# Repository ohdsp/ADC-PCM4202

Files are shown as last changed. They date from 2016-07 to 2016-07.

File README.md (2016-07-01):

# [Open Hardware DSP Platform](http://www.ohdsp.org)
## PCM4202 ADC with differential inputs
### Revision 2.0
###### ADC-PCM4202 (KiCad 4.0.2-stable)
---
# README
### Disclaimer
Copyright Paul Janicki 2016

Licensed under the TAPR Open Hardware License (www.tapr.org/OHL)

This documentation is distributed WITHOUT ANY EXPRESS OR IMPLIED WARRANTY, INCLUDING OF MERCHANTABILITY, SATISFACTORY QUALITY AND FITNESS FOR A PARTICULAR PURPOSE.

### What is this repository?

**Quick summary**

This is a differential stereo input PCM4202 ADC. This is designed as part the Open Hardware DSP Platform.  

The PCM4202 is a hardware controlled Delta-Sigma ADC.

This repository contains the KiCad design files, manufacturing Gerber/drill files, and PDF/drawing files for this board.

### What is the project folder structure?
Most folder names are self explanatory. Starting from the top level: \
*ADC-PCM4202*
+ *Bill of Materials*  - This contains the bill of materials in CVS, LibreOffice Calc and XML formats
+ *Drawings*
    + *PCB* - This contains SVG and PDF outputs of PCB copper layers and assembly drawings
    + *Schematics* - This contains the PDF schematic drawing
+ *Gerbers* - This contains the PCB Gerbers and drill drawings for manufacture, there is also a zip file ready to send to most manufacturers
+ *KiCad* - This contains the original KiCad schematic and PCB design files

### How do I get set up?

**Summary of set up**

1. Set your self up a directory on a local disk, something simple will make life easier (eg C:\Electronics on Windows as used here), but anywhere will do just fine.
2. Download the Kicad-Libs from [https://github.com/ohdsp/KiCad-Libs](https://github.com/ohdsp/KiCad-Libs) and place in C:\Electronics\Kicad-Libs (or your chosen folder) 
3. Create a OHDSP subdirectory in C:\Electronics (so C:\Electronics\OHDSP)
3. Download this project to C:\Electronics\OHDSP\ADC-PCM4202
4. Fire up Kicad
5. Open the main project file C:\Electronics\OHDSP\ADC-PCM4202\Schematics\ADC-PCM4202.pro
6. (Optional) Setup Pcbnew component library as below.
7. Do as you wish with the project, just keep it under TAPR Open Hardware License

Make sure your git setup doesn't exclude files used in the project (like .LIB files) or things may go wrong down the line.

**KiCad Library Configuration**

Note that you need to setup a Pcbnew library, but the eeschema libraries should work without any changes if you followed the instructions above.

To setup Pcbnew libraries:

In Pcbnew go to Preferences -> Footprint Libraries Manager. Under Global Libraries tab in the top list check if there is a nickname "MyKiCadLibs-Footprints" (usually at the end of the list). If there is but it points to the wrong place then change the Library Path to point to MyKiCadLibs-Footprints (eg C:\Electronics\KiCad-Libs\MyKiCadLibs-Footprints.pretty) folder for your setup. If this is missing you can use "Append with Wizard", choose "Files on my computer", click next, browse to library location (eg C:\Electronics\KiCad-Libs\MyKiCadLibs-Footprints.pretty) and select the folder MyKiCadLibs-Footprints.pretty, click next, check the Status column states OK and the Format is KiCad (if not re-download the library) and click next, then select "To global library configuration..." and click Finish.

To setup eeschema component libraries:
Either from KiCad project window go to Tools -> Run Library Editor OR under eeschema, go to Tools -> Library Editor. Then Preferences -> Component Libraries.

The top section "Component Library Files" should ideally contain only two libraries, the "power" library that ships with KiCad and "MyKiCadLibs-Lib" available from above. To setup MyKiCadLibs-Lib as a relative path under the "User defined search path" click add. Browse to the location of KiCad-Libs you download above (eg C:\Electronics\KiCad-Libs) and click "Select Folder". Say yes to add a relative path. Under component library files click add, browse to the KiCad-libs again (eg C:\Electronics\KiCad-Libs), select file "MyKiCadLibs-Lib.lib" and click open. MyKiCadLibs-lib should appear in the component library list with no path as it will be using the user defined search path set in the box below.

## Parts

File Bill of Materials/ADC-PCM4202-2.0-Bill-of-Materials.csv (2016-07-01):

Reference | Quantity | Footprint | Value | Description | Voltage | Size | Current | Type | Tolerance | Power
C201 C202 C210 C215 C217 | 5 | CAP-TH-D8mmP3.5mm | 220u | 'Aluminium electrolytic low impedance capacitor - eg Panasonic FC or FR parts | '25V | '3.5mm Pitch, 8mm Diameter | ' | ' | ' | '
C203 C204 C211 C218 C219 C224 | 6 | SMD-0805 | 22u | 'Ceramic capacitor | '25V | '0805 | ' | 'X5R | '20% | '
C205 C206 C214 C220 C221 C225 C228 C233 C234 C237 C238 C303 C307 C310 C311 C314 C318 C322 C323 C324 C327 C329 C330 C401 C403 C404 C406 C407 C412 C413 C422 C423 C426 C427 C428 C429 C438 C439 C442 C443 C444 C445 C448 C449 C454 C455 | 46 | SMD-0805 | 100n | 'Ceramic capacitor | '50V | '0805 | ' | 'X7R | '10% | '
C208 C209 C216 C222 C223 C229 C235 C306 C309 C312 C316 C319 C328 C405 C440 C441 C450 C451 C456 C457 | 20 | SMD-0805 | 10n | 'Ceramic capacitor | '50V | '0805 | ' | 'X7R | '10% | '
C207 C212 C213 C301 C315 C408 C409 C410 C411 | 9 | SMD-0805 | 100p | 'Ceramic capacitor | '50V | '0805 | ' | 'C0G | '5% | '
C226 C230 C302 C304 C317 C325 | 6 | CAP-TH-D6.3mmP2.5mm | 220u | 'Aluminium electrolytic low impedance capacitor - eg Panasonic FC or FR parts | '10V | '2.5mm Pitch, 6.3mm Diameter | ' | ' | ' | '
C227 C231 C305 C308 C320 C321 | 6 | SMD-0805 | 22u | 'Ceramic capacitor | '10V | '0805 | ' | 'X5R | '20% | '
C232 C236 C313 C424 C425 C430 C431 | 7 | SMD-0805 | 10u | 'Ceramic capacitor | '10V | '0805 | ' | 'X5R | '20% | '
C326 | 1 | SMD-0805 | N/F | 'Ceramic capacitor | '50V | '0805 | ' | 'X7R | '10% | '
C402 C446 C447 | 3 | SMD-1206 | 10u | 'Ceramic capacitor | '35V | '1206 | ' | 'X5R | '20% | '
C414 C417 C418 C421 | 4 | CAP-TH-D10mmP5mm | 100u | 'Aluminium electrolytic - Panasonic FC, Audio Grade, or Bipolar part | '50V | '5mm Pitch, 10mm Diameter | ' | ' | ' | '
C415 C416 C419 C420 | 4 | CAP_TH_5mm | 100n | 'Polyester capacitor - 5mm pitch - 5.5mm width max | '63V | '5mm | ' | 'Film | '10% | '
C432 C433 C434 C435 | 4 | SMD-0805 | 47p | 'Ceramic capacitor | '50V | '0805 | ' | 'C0G | '5% | '
C436 C437 | 2 | SMD-0805 | 2n7 | 'Ceramic capacitor | '50V | '0805 | ' | 'C0G | '5% | '
C452 C453 | 2 | CAP-TH-D6.3mmP2.5mm | 47u | 'Aluminium electrolytic low impedance capacitor - eg Panasonic FC or FR parts | '10V | '2.5mm Pitch, 6.3mm Diameter | ' | ' | ' | '
D201 D202 D203 D204 D205 D206 D208 | 7 | DIODE-SOD-123 | SS14L | 'SS14L 1A 40V Schottky rectifier - Sub-SMA (SOD-123) | ' | ' | ' | ' | ' | '
D207 | 1 | SMD-1206 | Green LED 1206 | 'Green LED - SMD - Vf 1.8V to 2.2V | ' | '1206 | ' | ' | ' | '
D301 D302 | 2 | SMD-1206 | Red LED 1206 | 'Red LED - SMD - Vf 1.8V to 2.2V | ' | '1206 | ' | ' | ' | '
FID201 FID202 FID203 FID204 | 4 | FID-1MM-3MM | MNT_HOLE | 'Fiducial Marker | ' | ' | ' | ' | ' | '
JP301 JP302 JP303 JP304 JP305 JP306 JP307 P301 | 8 | CONN_SIL_2_1MM | CONN_2x1 | '1x2 2.54mm pitch pin header | ' | ' | ' | ' | ' | '
L201 L202 L203 L301 L302 | 5 | SMD-0805 | 600R@100MHz | 'Ferrite bead, current rating 0.3A or higher, 600R@100MHz | ' | '0805 | '=>0.3A | ' | ' | '
MNT201 MNT202 MNT203 MNT204 | 4 | MNT_HOLE_3.2mm | MNT_HOLE | 'Mounting Hole | ' | ' | ' | ' | ' | '
P201 P202 P203 | 3 | CONN-2WAY-2.54mm-3.81mm-SPACING | CONN_2x1 | '2 way screw terminal, any 2.54mm to 3.81mm pitch part | ' | ' | ' | ' | ' | '
P302 | 1 | CONN_SIL_3_1MM | N/F | '1x3 2.54mm pitch pin header | ' | ' | ' | ' | ' | '
P303 | 1 | CONN_DIL_2X5_BOX_1MM | CONN_02X05 | '2x5 2.54mm pitch box header | ' | ' | ' | ' | ' | '
P401 P402 | 2 | CONN_SIL_3_1MM | CONN_3x1 | '1x3 2.54mm pitch pin header | ' | ' | ' | ' | ' | '
R201 R202 R203 R306 R309 | 5 | SMD-0805 | 47 | 'Thick or thin film resistor | ' | '0805 | ' | ' | '1% | '100mW
R204 | 1 | SMD-0805 | 2k2 | 'Thick or thin film resistor | ' | '0805 | ' | ' | '1% | '100mW
R205 | 1 | SMD-0805 | 6k8 | 'Thick or thin film resistor | ' | '0805 | ' | ' | '1% | '100mW
R206 R324 R326 | 3 | SMD-0805 | 470 | 'Thick or thin film resistor | ' | '0805 | ' | ' | '1% | '100mW
R301 R302 R303 R304 R305 R307 R308 | 7 | SMD-0805 | 10k | 'Thick or thin film resistor | ' | '0805 | ' | ' | '1% | '100mW
R311 | 1 | SMD-0805 | 100k | 'Thick or thin film resistor | ' | '0805 | ' | ' | '1% | '100mW
R312 R318 R319 R320 R321 R322 | 6 | SMD-0805 | N/F | 'Thick or thin film resistor | ' | '0805 | ' | ' | '1% | '100mW
R313 R314 R315 | 3 | SMD-0805 | 0 | 'Thick or thin film resistor | ' | '0805 | ' | ' | '1% | '100mW
R316 | 1 | SMD-0805 | 75 | 'Thick or thin film resistor | ' | '0805 | ' | ' | '1% | '100mW
R317 | 1 | SMD-0805 | 100R | 'Thick or thin film resistor | ' | '0805 | ' | ' | '1% | '100mW
R310 R323 R325 | 3 | SMD-0805 | 1k | 'Thick or thin film resistor | ' | '0805 | ' | ' | '1% | '100mW
R403 R404 R405 R406 | 4 | SMD-1206 | 100 | 'MELF0204 1% =>250mW or 1206 1% =>250mW | ' | '1206 | ' | ' | '1% | '250mW
R407 R408 R409 R410 | 4 | SMD-1206 | 100k | 'MELF0204 1% =>250mW or 1206 1% =>250mW | ' | '1206 | ' | ' | '1% | '250mW
R411 R412 R413 R414 R415 R416 R417 R418 | 8 | SMD-1206 | 4k7 | 'MELF0204 1% =>250mW or 1206 1% =>250mW | ' | '1206 | ' | ' | '1% | '250mW
R401 R402 R419 R420 R421 R422 | 6 | SMD-1206 | 10k | 'MELF0204 1% =>250mW or 1206 1% =>250mW | ' | '1206 | ' | ' | '1% | '250mW
R423 R424 R425 R426 | 4 | SMD-1206 | 40R2 | 'MELF0204 1% =>250mW or 1206 1% =>250mW | ' | '1206 | ' | ' | '1% | '250mW
R427 R428 R429 R430 | 4 | SMD-1206 | 1k | 'MELF0204 1% =>250mW or 1206 1% =>250mW | ' | '1206 | ' | ' | '1% | '250mW
TR301 TR302 | 2 | IC-SOT23 | BC847 | '45 V, 100 mA NPN general-purpose transistors | ' | ' | ' | ' | ' | '
U201 | 1 | IC-SOT-223 | TLV1117LV33DCY | 'TLV1117LV 1-A, Positive Fixed-Voltage, Low-Dropout Regulator - Fixed 3V3 | ' | ' | ' | ' | ' | '
U202 | 1 | IC-SOT223-6 | TPS7A4501 | 'TPS7A45xx Low-Noise Fast-Transient-Response 1.5-A Low-Dropout Voltage Regulator - Adjustable | ' | ' | ' | ' | ' | '
U301 | 1 | IC-SSOP28 | PCM4202DBT | 'High-Performance 24-Bit, 216kHz Sampling Stereo Audio Analog-to-Digital Converter | ' | ' | ' | ' | ' | '
U302 | 1 | IC-SOT143 | ADM811TART | 'Microprocessor Supervisory - 3V08 Typical Threshold | ' | ' | ' | ' | ' | '
U401 U402 U403 U404 U405 U406 | 6 | IC_SOIC_8 | TLE2071 | 'LOW-NOISE HIGH-SPEED JFET-INPUT OPERATIONAL AMPLIFIERS - SINGLE | ' | ' | ' | ' | ' | '

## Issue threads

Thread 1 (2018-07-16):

I don't think the preamp section does what it should do

mrnuke, 2018-07-16:
I'd expect the preamp to the ADC to do several things, of which:

1. Shift an input voltage of 0V to Vcom
2. Maintain phase relationship between input and output signals

I'll take one half of the preamp for demonstration purposes:

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

Under normal operating conditions Vc = V+, and the opamp does its thing to keep V- = Vc. Looking at a current going throgh R411 and R419 we get:

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

We can solve this for Vo, and rearrange things a bit to get:

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

It could be that I'm just reading the schematic completely wrong, but I doubt it. This fails point (1) because it applies a non-unity gain to Vcom. It fails point (2) because it inverts the phase of the signal -- negative gain wrt Vi.

(2) is easy to fix, just swap the ANAL+/- connections.
(1) can be fixed by applying Vcom to a summing junction at the inverting input. However, in that case, it's probably better to use an instrumentation amplifier topology, and Vcom might need to be buffered

ohdsp, 2018-07-16:
C414 gives unity gain at DC. See examples for chips like the PCM4220.

mrnuke, 2018-07-16:
Oh, DUH. You are right. I can't ignore C414 like I did, because it blocks DC currents. Thank you for clarifying this, and my apologies for raising a false alarm. There's still the phase reversal issue (which is correctly handled in the PCM4220 example circuit).

ohdsp, 2018-07-16:
PCM4220 has both inverting/non-inverting options as examples. You do not need to maintain the phase, and with a differential input who's to say it was wired correctly anyway. With a DSP in the middle you can just hit the invert button. There many technical arguments for inverting/non-inverting. In this instance I can achieve gains <1 if needed.

Closed 2018-07-16.

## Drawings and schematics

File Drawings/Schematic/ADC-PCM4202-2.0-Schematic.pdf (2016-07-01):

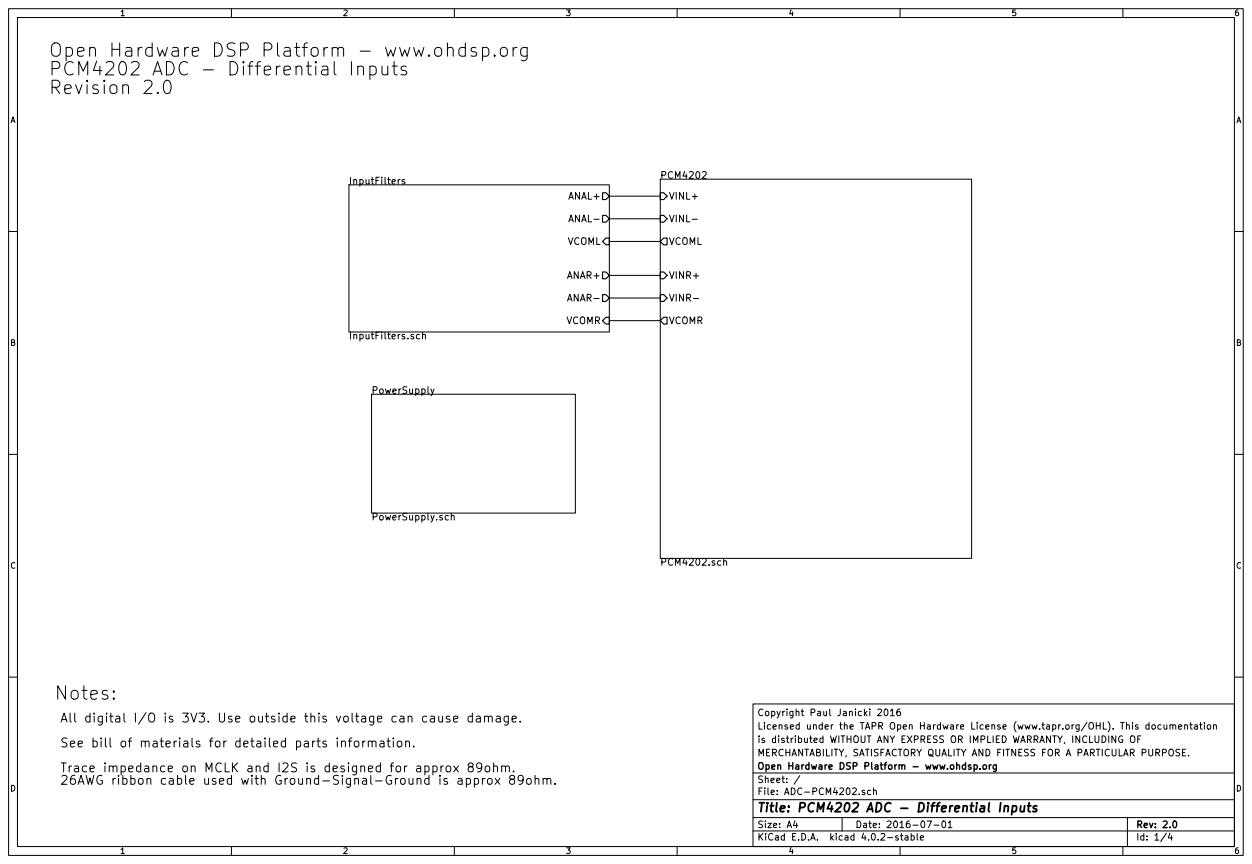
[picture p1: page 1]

Open Hardware DSP Platform - www.ohdsp.org
PCM4202 ADC - Differential Inputs
Revision 2.0

PCM4202
PCM4202.sch VINR+ VINR- VINL+ VINL- VCOML

VCOML ANAL+ ANAL- ANAR+ ANAR- VCOMR

All digital I/O is 3V3. Use outside this voltage can cause damage.
See bill of materials for detailed parts information.
Trace impedance on MCLK and I2S is designed for approx 89ohm.
26AWG ribbon cable used with Ground-Signal-Ground is approx 89ohm.

Copyright Paul Janicki 2016
Licensed under the TAPR Open Hardware License (www.tapr.org/OHL). This documentation
is distributed WITHOUT ANY EXPRESS OR IMPLIED WARRANTY, INCLUDING OF
MERCHANTABILITY, SATISFACTORY QUALITY AND FITNESS FOR A PARTICULAR PURPOSE.
File: ADC-PCM4202.sch Sheet: / Open Hardware DSP Platform - www.ohdsp.org

Id: 1/4 Title: PCM4202 ADC - Differential Inputs

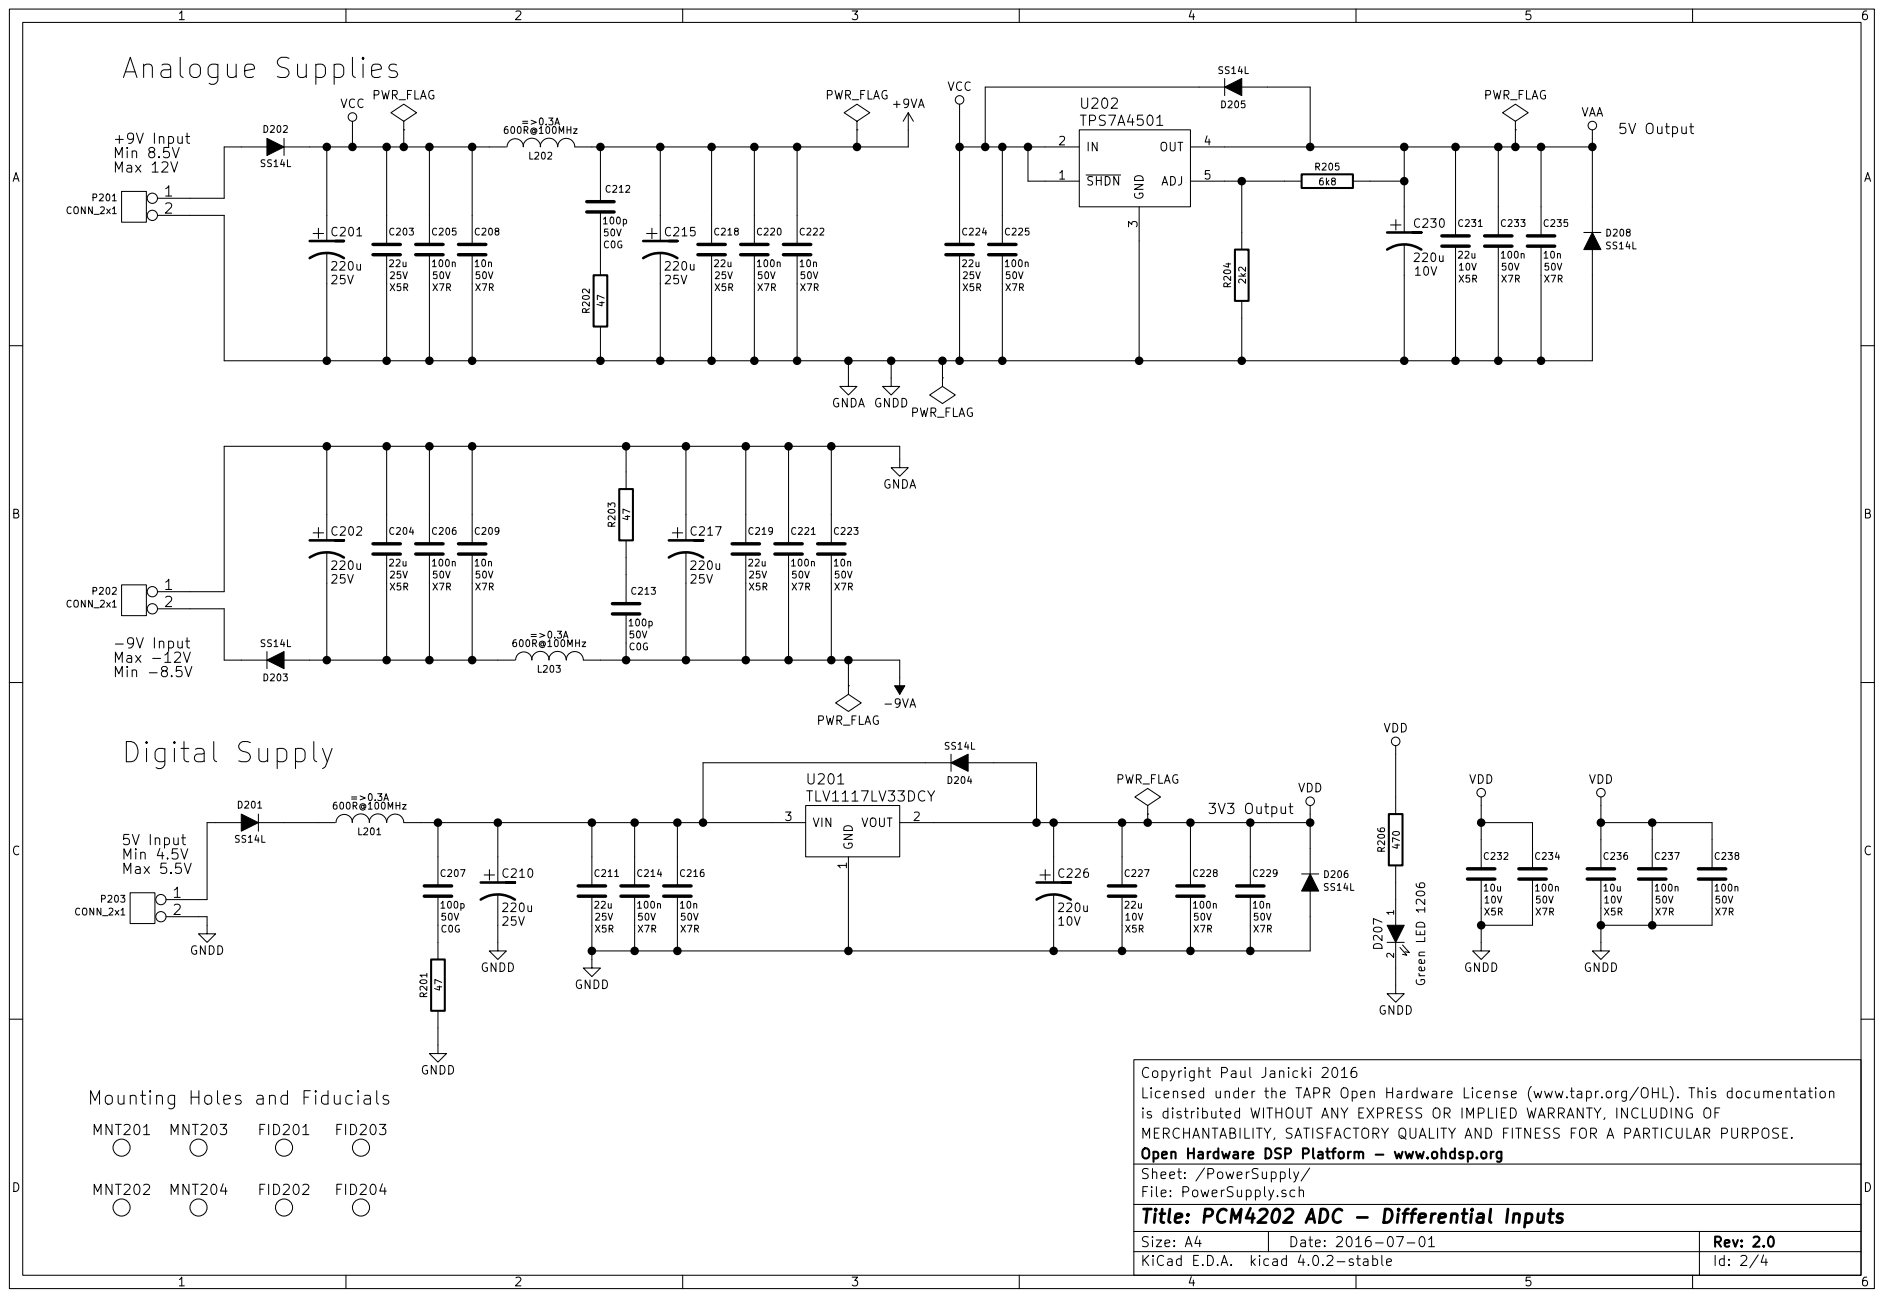
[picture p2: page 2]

Copyright Paul Janicki 2016
Licensed under the TAPR Open Hardware License (www.tapr.org/OHL). This documentation
is distributed WITHOUT ANY EXPRESS OR IMPLIED WARRANTY, INCLUDING OF
MERCHANTABILITY, SATISFACTORY QUALITY AND FITNESS FOR A PARTICULAR PURPOSE.
Open Hardware DSP Platform - www.ohdsp.org
Sheet: /PowerSupply/
File: PowerSupply.sch
Id: 2/4 Title: PCM4202 ADC - Differential Inputs

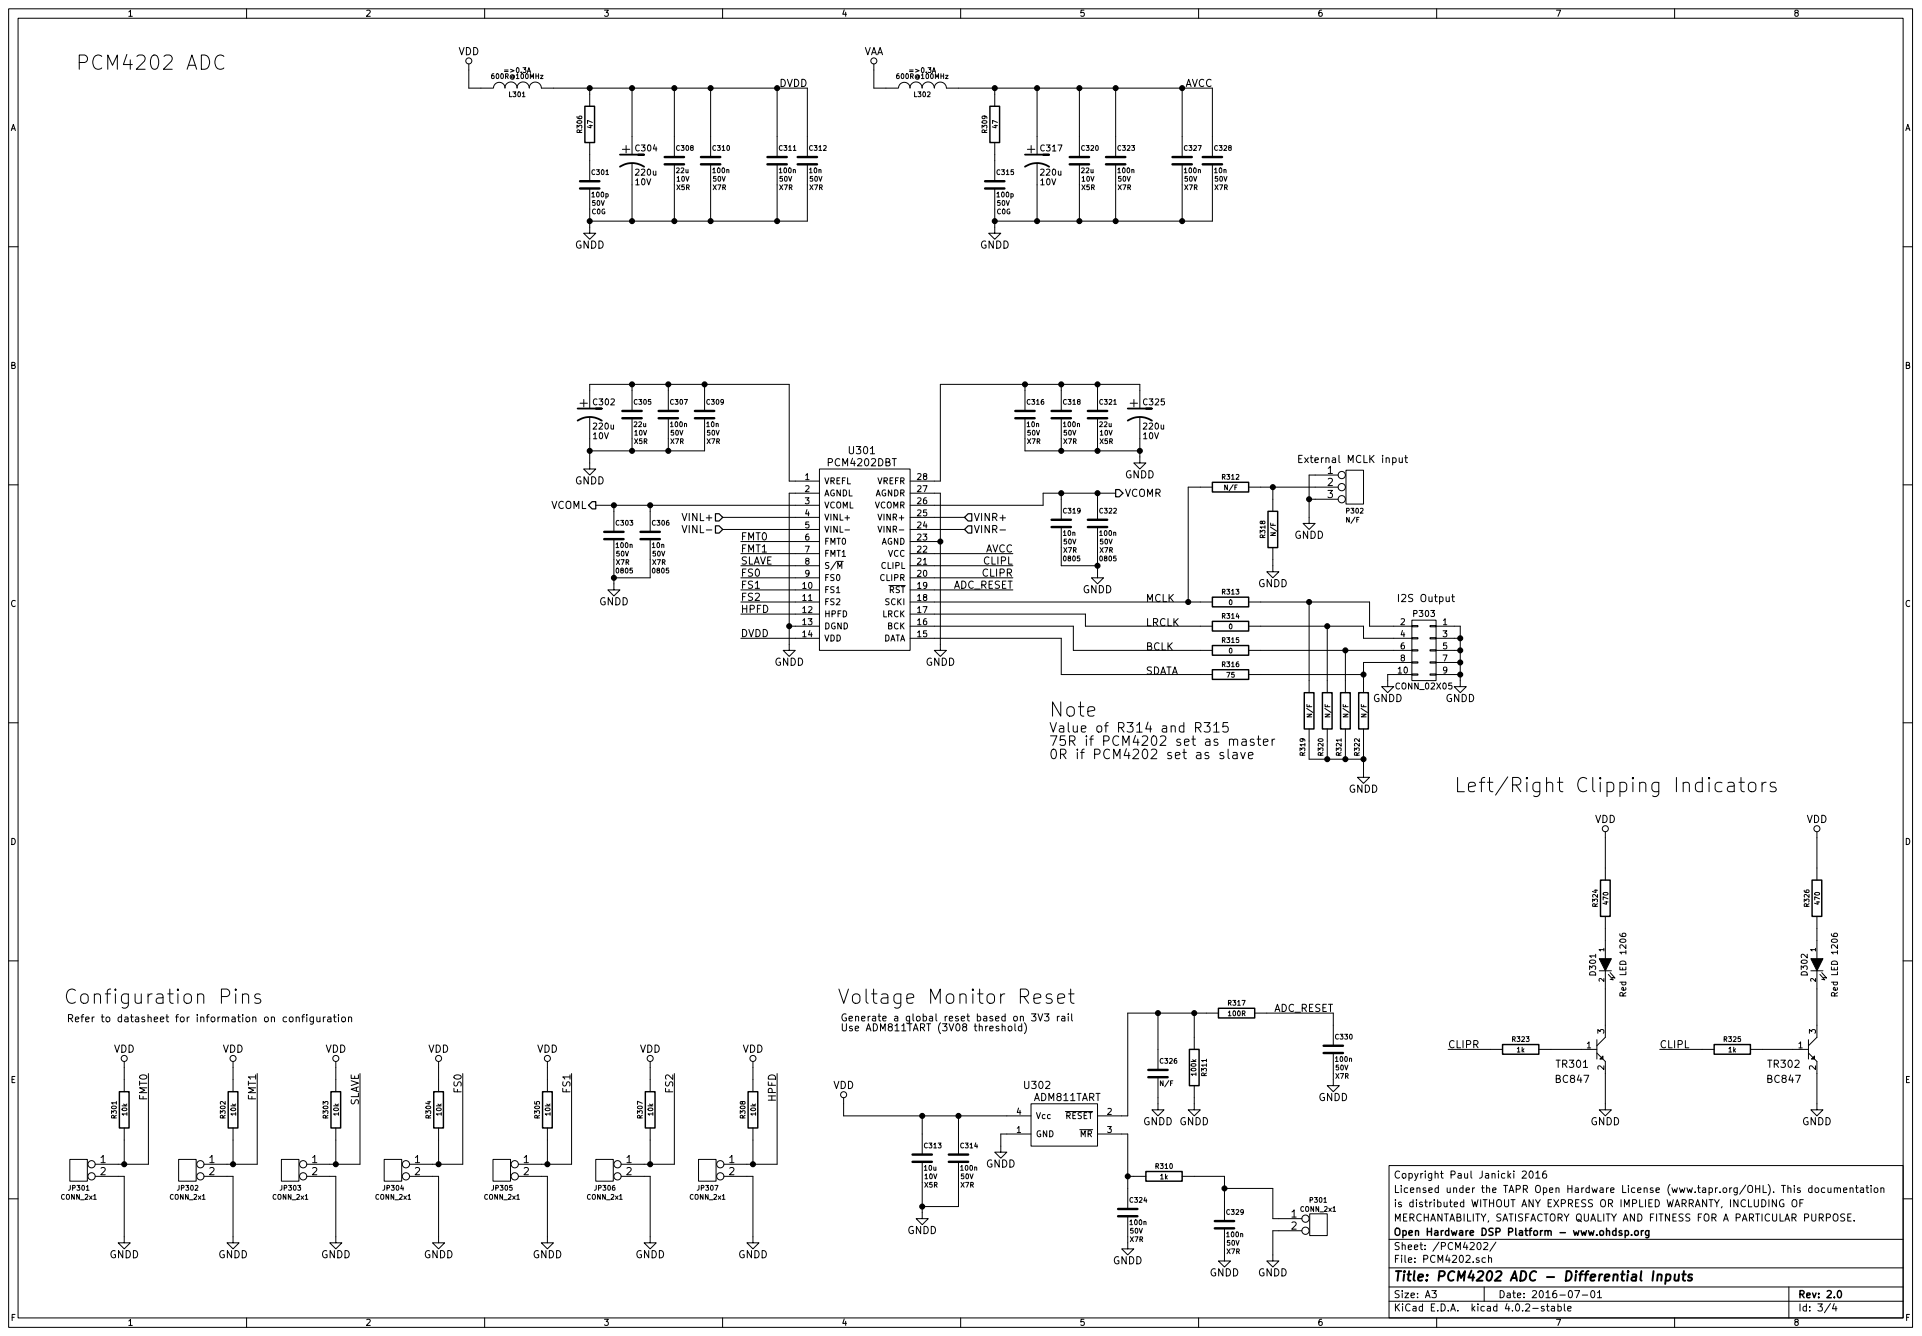
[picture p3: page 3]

VINR+ VINR- VINL+ VINL-

Note
Value of R314 and R315
75R if PCM4202 set as master
0R if PCM4202 set as slave

Left/Right Clipping Indicators

1 2 D301 Red LED 1206 VDD GNDD

Refer to datasheet for information on configuration

Generate a global reset based on 3V3 rail
Use ADM811TART (3V08 threshold)

Copyright Paul Janicki 2016
Licensed under the TAPR Open Hardware License (www.tapr.org/OHL). This documentation
is distributed WITHOUT ANY EXPRESS OR IMPLIED WARRANTY, INCLUDING OF
MERCHANTABILITY, SATISFACTORY QUALITY AND FITNESS FOR A PARTICULAR PURPOSE.
File: PCM4202.sch Sheet: /PCM4202/ Open Hardware DSP Platform - www.ohdsp.org

Id: 3/4 Title: PCM4202 ADC - Differential Inputs

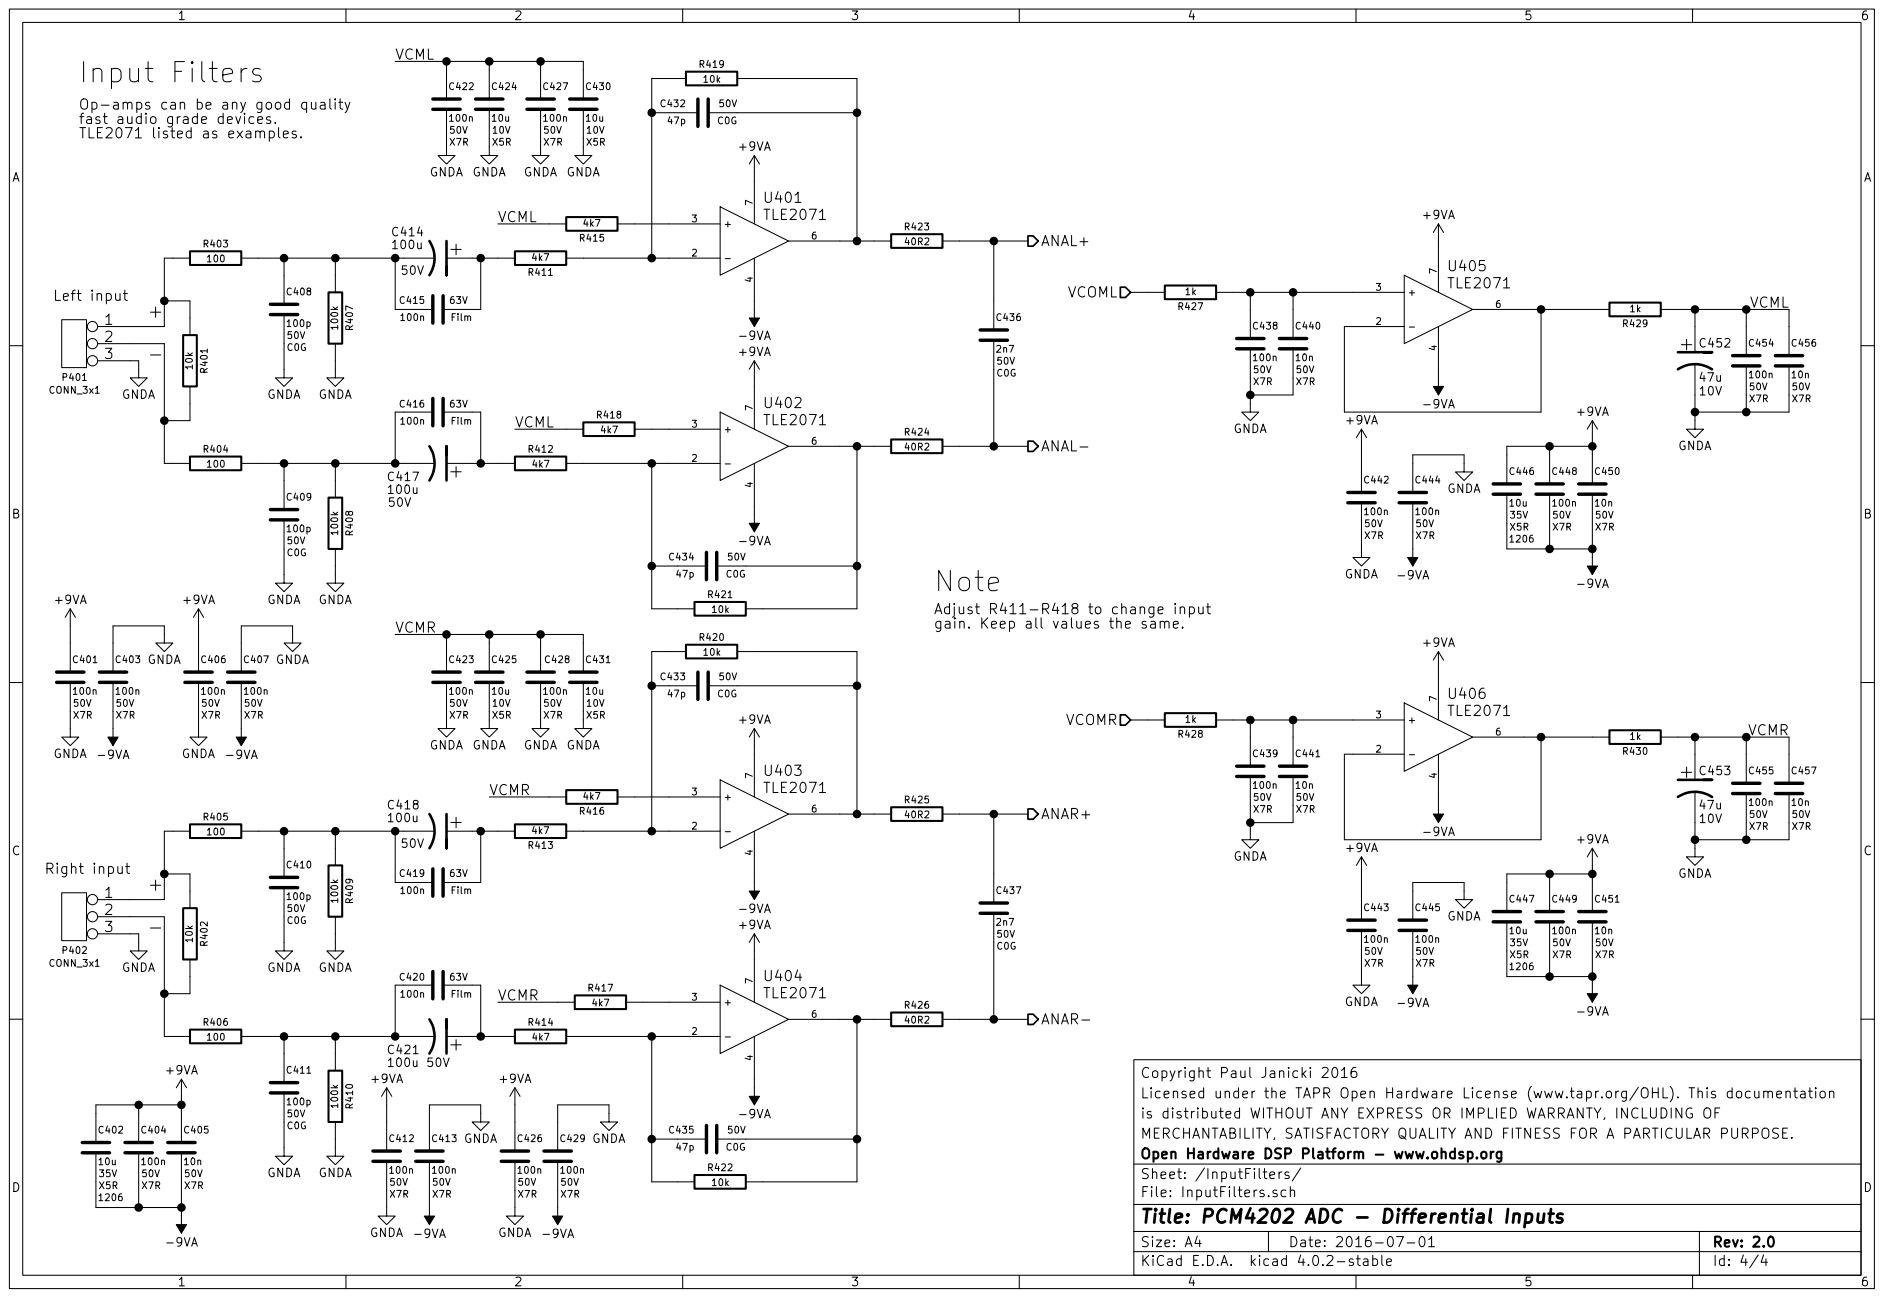
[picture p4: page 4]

Op-amps can be any good quality
fast audio grade devices.
TLE2071 listed as examples. R403

gain. Keep all values the same.

Copyright Paul Janicki 2016 GNDA

Licensed under the TAPR Open Hardware License (www.tapr.org/OHL). This documentation
is distributed WITHOUT ANY EXPRESS OR IMPLIED WARRANTY, INCLUDING OF
MERCHANTABILITY, SATISFACTORY QUALITY AND FITNESS FOR A PARTICULAR PURPOSE.
Open Hardware DSP Platform - www.ohdsp.org
Sheet: /InputFilters/
File: InputFilters.sch
Id: 4/4 Title: PCM4202 ADC - Differential Inputs

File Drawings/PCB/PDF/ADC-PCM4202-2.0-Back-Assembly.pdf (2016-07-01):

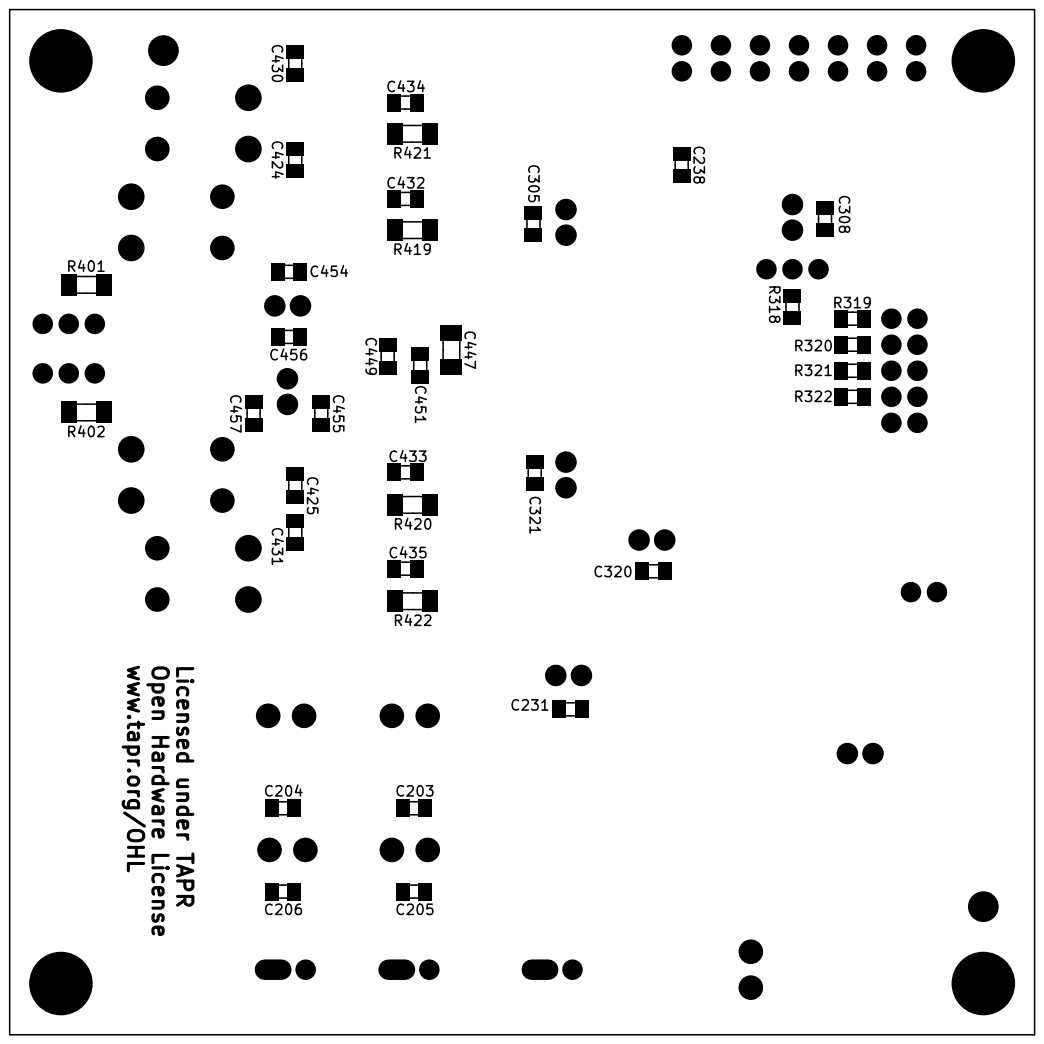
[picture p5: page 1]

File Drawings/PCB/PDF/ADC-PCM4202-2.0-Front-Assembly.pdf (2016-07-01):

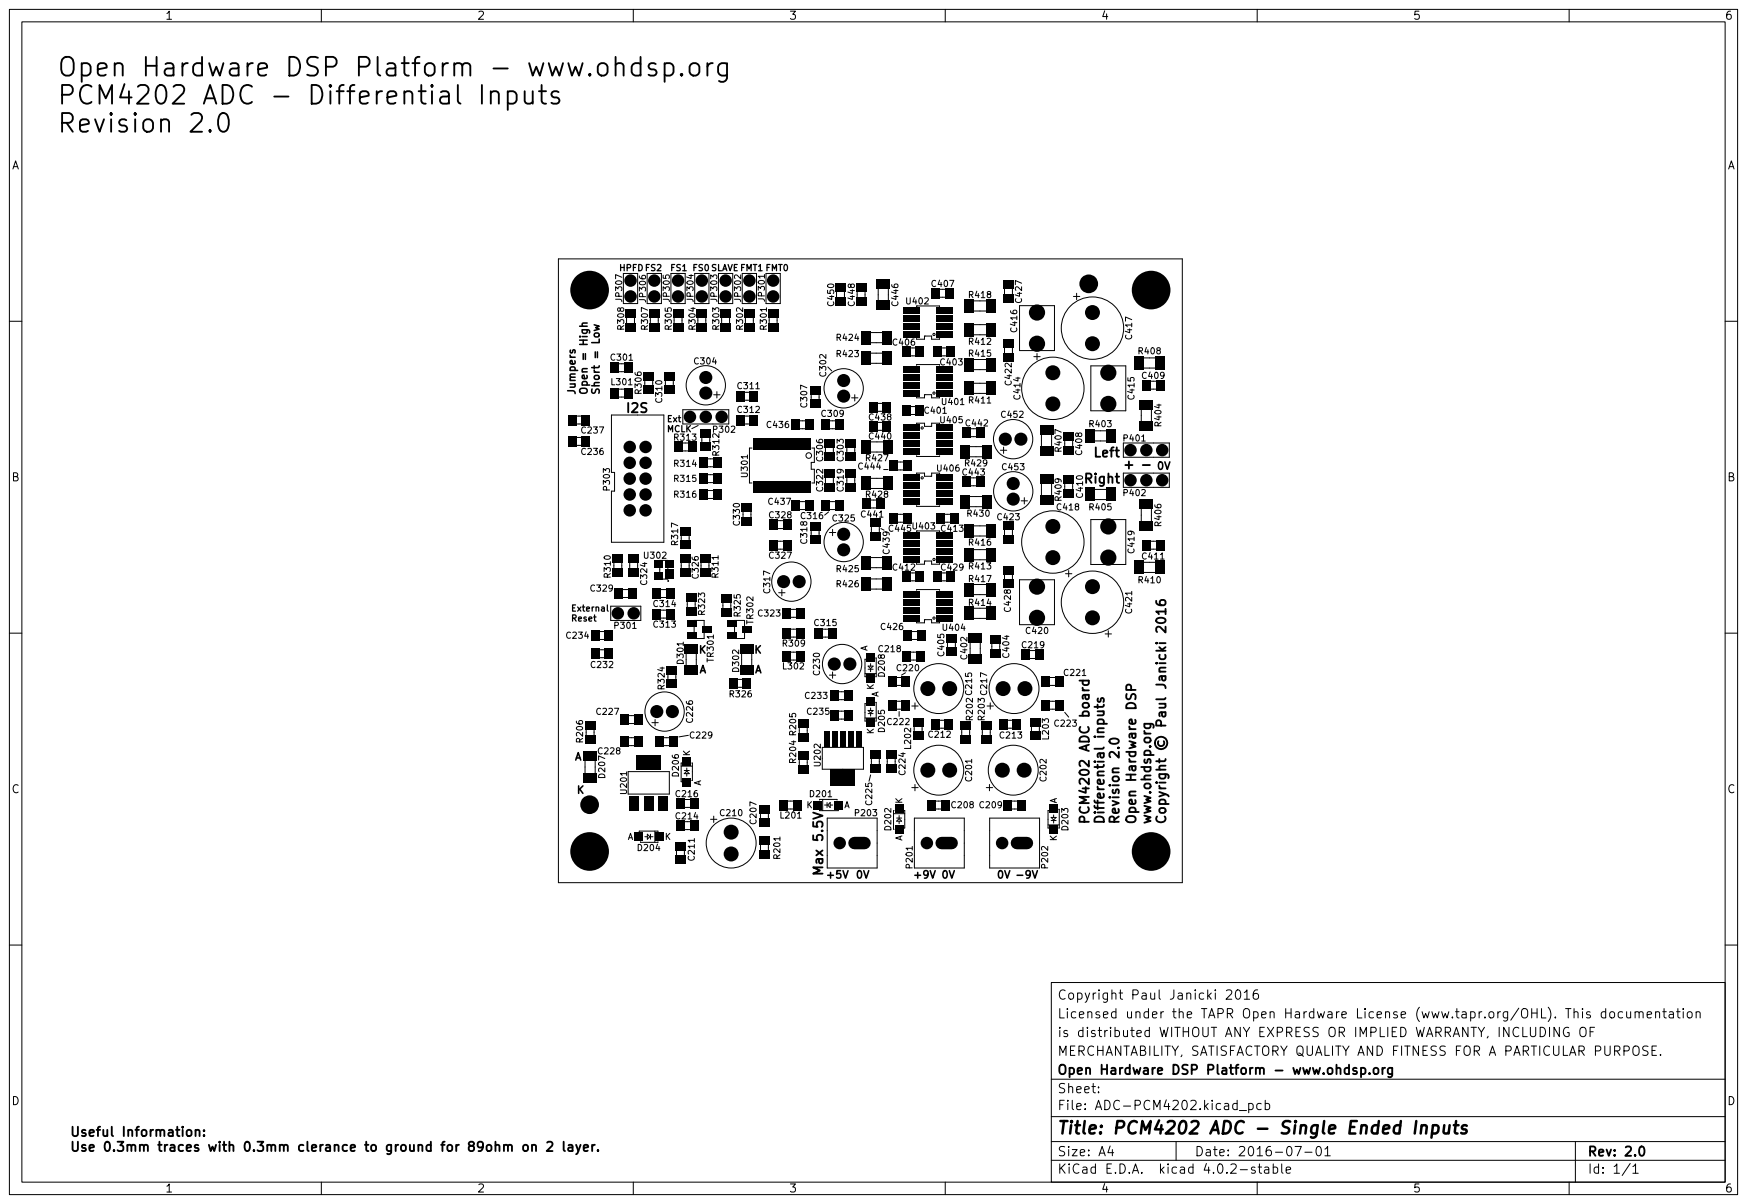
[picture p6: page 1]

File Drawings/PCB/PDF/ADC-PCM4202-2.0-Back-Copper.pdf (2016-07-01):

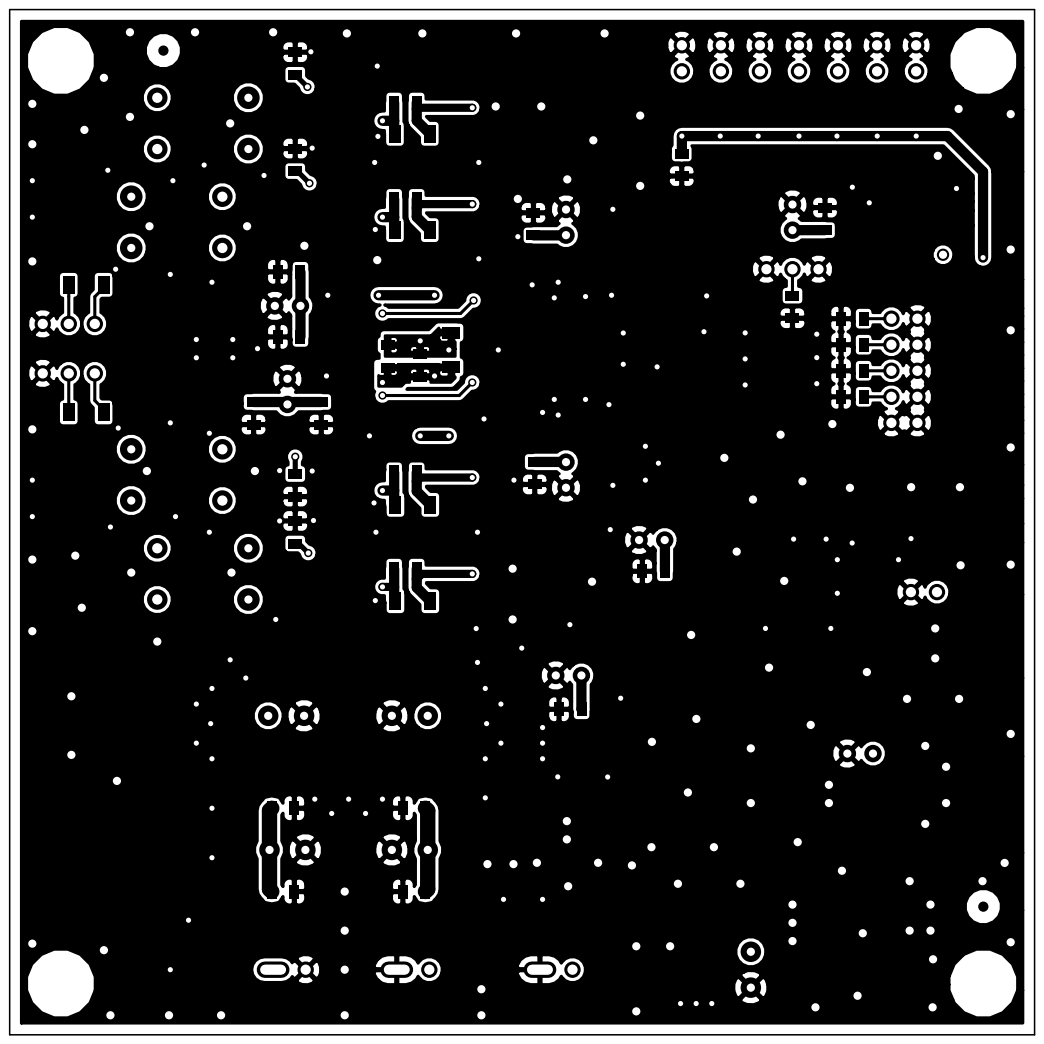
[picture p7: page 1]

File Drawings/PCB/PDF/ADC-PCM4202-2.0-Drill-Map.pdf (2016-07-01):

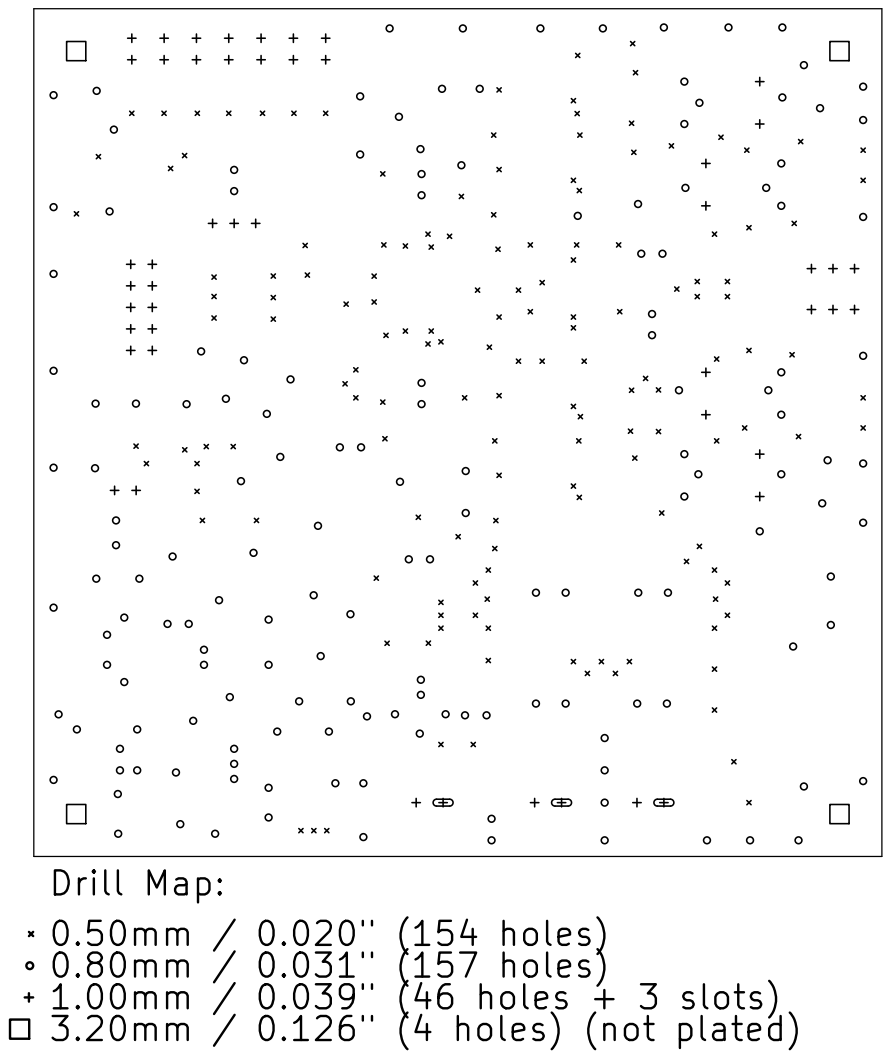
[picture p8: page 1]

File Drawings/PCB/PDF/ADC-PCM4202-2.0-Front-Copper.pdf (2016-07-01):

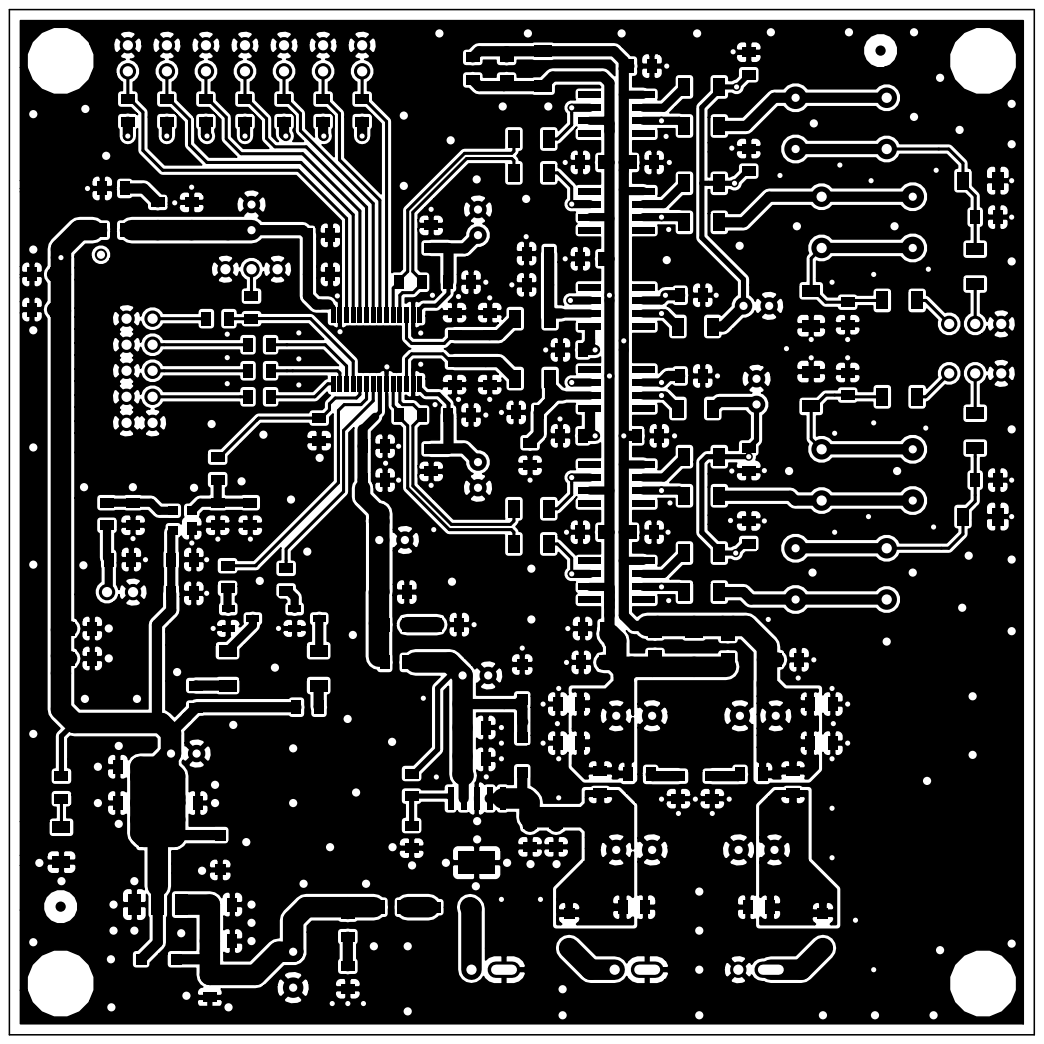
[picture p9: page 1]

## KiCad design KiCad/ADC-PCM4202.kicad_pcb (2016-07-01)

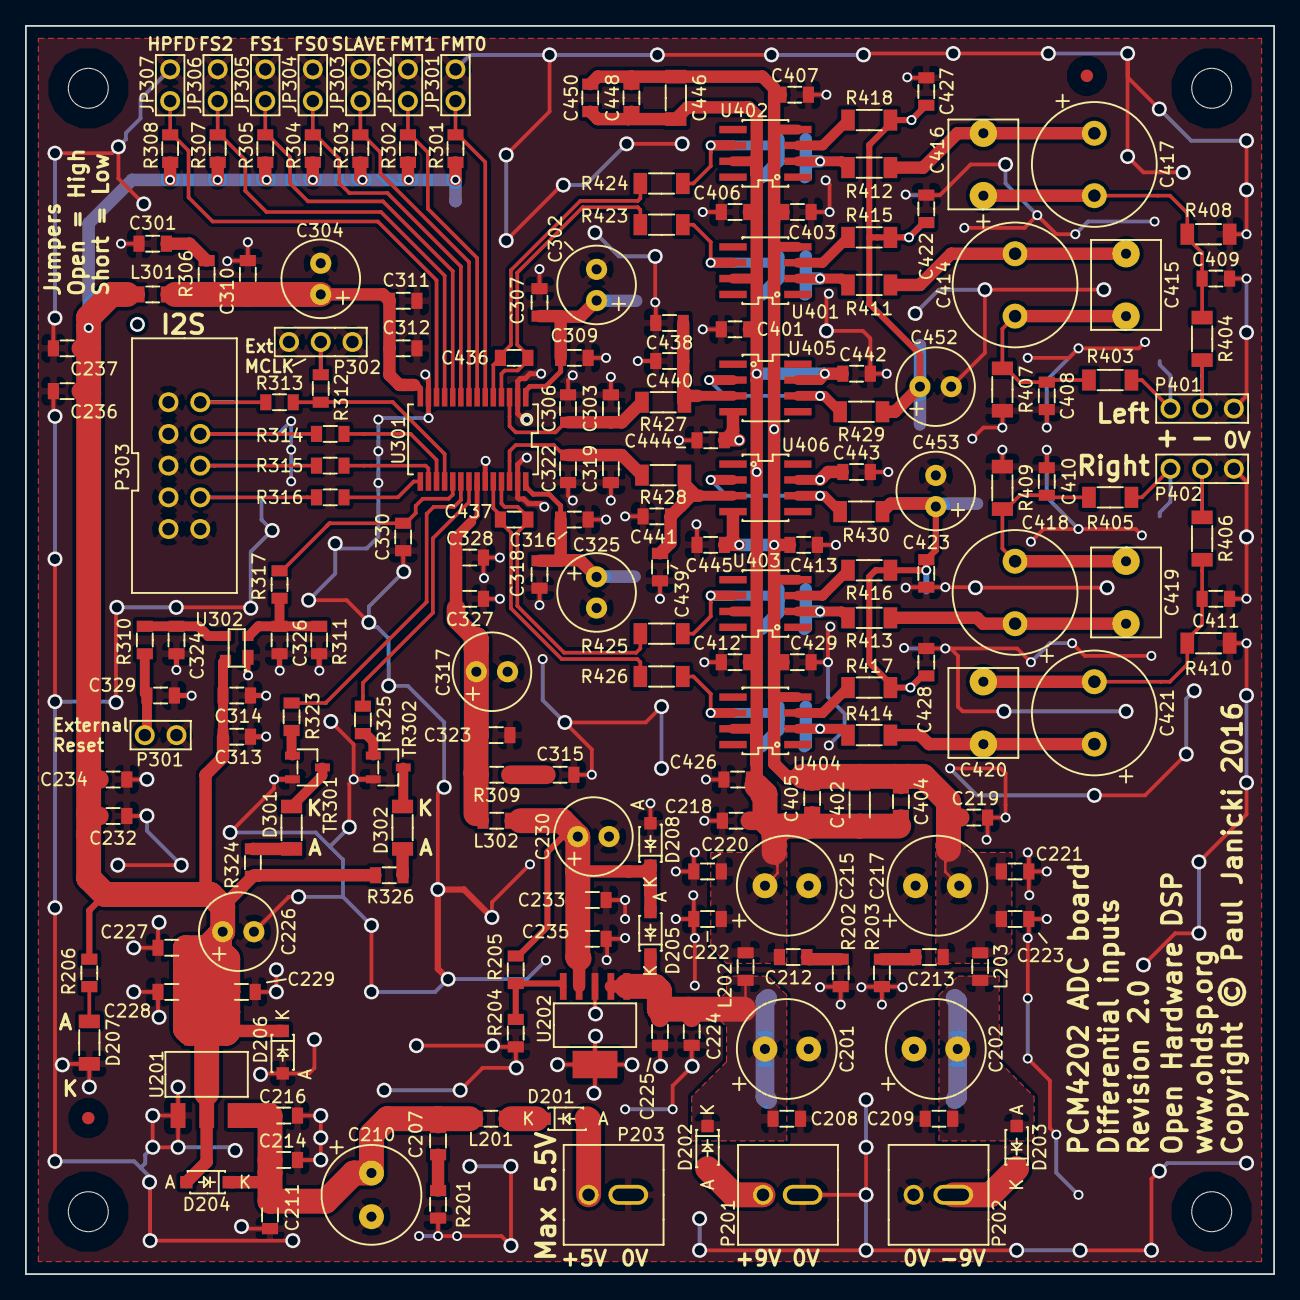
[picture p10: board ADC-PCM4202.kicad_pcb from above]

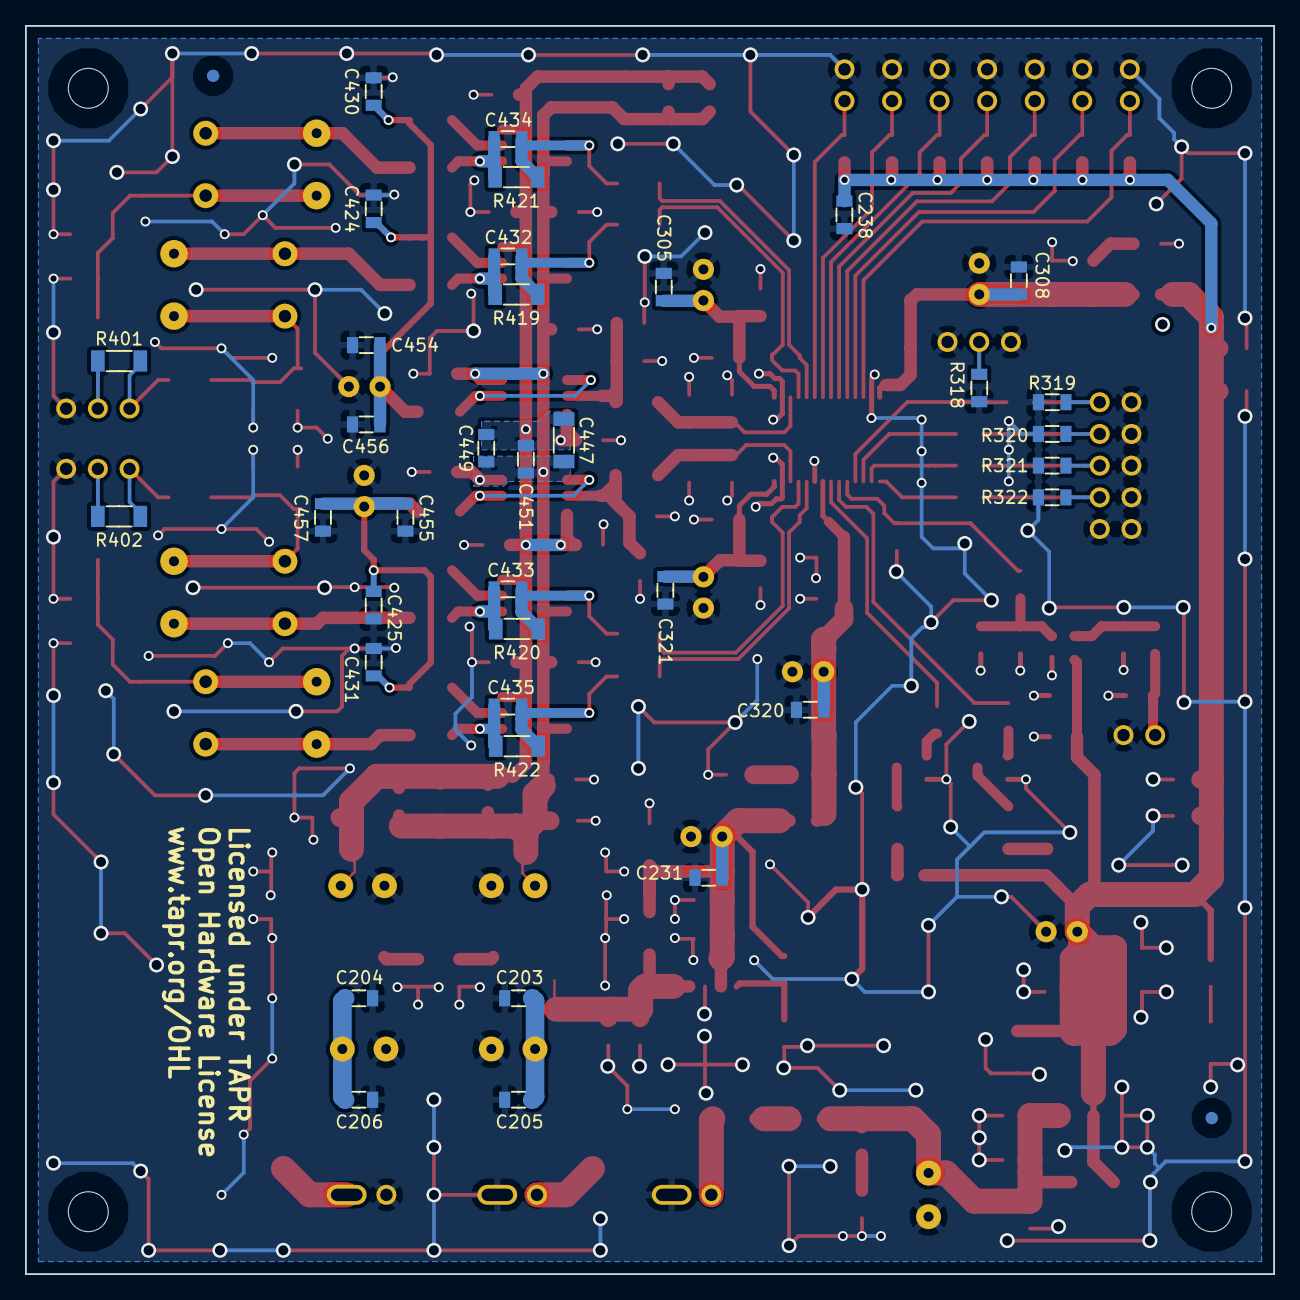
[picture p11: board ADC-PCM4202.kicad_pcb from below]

Board: 2 copper layers, 100.0 x 100.0 mm, 237 parts (38 on the bottom side), 87 nets.

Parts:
C201, C202, C210, C215, C217: 220u; CAP-TH-D8mmP3.5mm
C203, C204, C211, C218, C219, C224, C227, C231, C305, C308, C320, C321: 22u; SMD-0805
C205, C206, C214, C220, C221, C225, C228, C233, C234, C237, C238, C303, C307, C310, C311, C314, C318, C322, C323, C324, C327, C329, C330, C401, C403, C404, C406, C407, C412, C413, C422, C423, C426, C427, C428, C429, C438, C439, C442, C443, C444, C445, C448, C449, C454, C455: 100n; SMD-0805
C207, C212, C213, C301, C315, C408, C409, C410, C411: 100p; SMD-0805
C208, C209, C216, C222, C223, C229, C235, C306, C309, C312, C316, C319, C328, C405, C440, C441, C450, C451, C456, C457: 10n; SMD-0805
C226, C230, C302, C304, C317, C325: 220u; CAP-TH-D6.3mmP2.5mm
C232, C236, C313, C424, C425, C430, C431: 10u; SMD-0805
C326: N/F; SMD-0805
C402, C446, C447: 10u; SMD-1206
C414, C417, C418, C421: 100u; CAP-TH-D10mmP5mm
C415, C416, C419, C420: 100n; CAP_TH_5mm
C432, C433, C434, C435: 47p; SMD-0805
C436, C437: 2n7; SMD-0805
C452, C453: 47u; CAP-TH-D6.3mmP2.5mm
D201, D202, D203, D204, D205, D206, D208: SS14L; DIODE-SOD-123
D207: Green LED 1206; SMD-1206
D301, D302: Red LED 1206; SMD-1206
FID201, FID202, FID203, FID204: MNT_HOLE; FID-1MM-3MM
JP301, JP302, JP303, JP304, JP305, JP306, JP307: CONN_2x1; CONN_SIL_2_1MM
L201, L202, L203, L301, L302: 600R@100MHz; SMD-0805
MNT201, MNT202, MNT203, MNT204: MNT_HOLE; MNT_HOLE_3.2mm
P201, P202, P203: CONN_2x1; CONN-2WAY-2.54mm-3.81mm-SPACING
P301: CONN_2x1; CONN_SIL_2_1MM
P302: N/F; CONN_SIL_3_1MM
P303: CONN_02X05; CONN_DIL_2X5_BOX_1MM
P401, P402: CONN_3x1; CONN_SIL_3_1MM
R201, R202, R203, R306, R309: 47; SMD-0805
R204: 2k2; SMD-0805
R205: 6k8; SMD-0805
R206, R324, R326: 470; SMD-0805
R301, R302, R303, R304, R305, R307, R308: 10k; SMD-0805
R310, R323, R325: 1k; SMD-0805
R311: 100k; SMD-0805
R312, R318, R319, R320, R321, R322: N/F; SMD-0805
R313, R314, R315: 0; SMD-0805
R316: 75; SMD-0805
R317: 100R; SMD-0805
R401, R402, R419, R420, R421, R422: 10k; SMD-1206
R403, R404, R405, R406: 100; SMD-1206
R407, R408, R409, R410: 100k; SMD-1206
R411, R412, R413, R414, R415, R416, R417, R418: 4k7; SMD-1206
R423, R424, R425, R426: 40R2; SMD-1206
R427, R428, R429, R430: 1k; SMD-1206
TR301, TR302: BC847; IC-SOT23
U201: TLV1117LV33DCY; IC-SOT-223
U202: TPS7A4501; IC-SOT223-6
U301: PCM4202DBT; IC-SSOP28
U302: ADM811TART; IC-SOT143
U401, U402, U403, U404, U405, U406: TLE2071; IC_SOIC_8

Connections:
+9VA: C212.1, C215.1, C218.1, C220.1, C222.1, C401.1, C402.1, C404.1, C405.1, C406.1, C412.1, C426.1, C442.1, C443.1, C446.1, C447.1, C448.1, C449.1, C450.1, C451.1, L202.2, U401.7, U402.7, U403.7, U404.7, U405.7, U406.7
-9VA: C213.2, C217.2, C219.2, C221.2, C223.2, C402.2, C403.2, C404.2, C405.2, C407.2, C413.2, C429.2, C444.2, C445.2, C446.2, C447.2, C448.2, C449.2, C450.2, C451.2, L203.2, U401.4, U402.4, U403.4, U404.4, U405.4, U406.4
/InputFilters/ANAL+: C436.1, R423.1, U301.4
/InputFilters/ANAL-: C436.2, R424.1, U301.5
/InputFilters/ANAR+: C437.1, R425.1, U301.25
/InputFilters/ANAR-: C437.2, R426.1, U301.24
/InputFilters/VCML: C422.1, C424.1, C427.1, C430.1, C452.1, C454.1, C456.1, R415.1, R418.2, R429.1
/InputFilters/VCMR: C423.1, C425.1, C428.1, C431.1, C453.1, C455.1, C457.1, R416.1, R417.2, R430.1
/InputFilters/VCOML: C303.1, C306.1, R427.2, U301.3
/InputFilters/VCOMR: C319.1, C322.1, R428.2, U301.26
/PCM4202/ADC_RESET: C330.1, R317.1, U301.19
/PCM4202/AVCC: C317.1, C320.1, C323.1, C327.1, C328.1, L302.2, R309.1, U301.22
/PCM4202/CLIPL: R325.1, U301.21
/PCM4202/CLIPR: R323.1, U301.20
/PCM4202/DVDD: C304.1, C308.1, C310.1, C311.1, C312.1, L301.2, R306.1, U301.14
/PCM4202/FMT0: JP301.1, R301.2, U301.6
/PCM4202/FMT1: JP302.1, R302.2, U301.7
/PCM4202/FS0: JP304.1, R304.2, U301.9
/PCM4202/FS1: JP305.1, R305.2, U301.10
/PCM4202/FS2: JP306.1, R307.2, U301.11
/PCM4202/HPFD: JP307.1, R308.2, U301.12
/PCM4202/SLAVE: JP303.1, R303.2, U301.8
GNDA: C201.2, C202.1, C203.2, C204.1, C205.2, C206.1, C208.2, C209.1, C210.2, C211.2, C214.2, C215.2, C216.2, C217.1, C218.2, C219.1, C220.2, C221.1, C222.2, C223.1, C224.2, C225.2, C226.2, C227.2, C228.2, C229.2, C230.2, C231.2, C232.2, C233.2, C234.2, C235.2, C236.2, C237.2, C238.2, C301.2, C302.2, C303.2, C304.2, C305.2, C306.2, C307.2, C308.2, C309.2, C310.2, C311.2, C312.2, C313.2, C314.2, C315.2, C316.2, C317.2, C318.2, C319.2, C320.2, C321.2, C322.2, C323.2, C324.2, C325.2, C326.2, C327.2, C328.2, C329.2, C330.2, C401.2, C403.1, C406.2, C407.1, C408.2, C409.2, C410.2, C411.2, C412.2, C413.1, C422.2, C423.2, C424.2, C425.2, C426.2, C427.2, C428.2, C429.1, C430.2, C431.2, C438.2, C439.2, C440.2, C441.2, C442.2, C443.2, C444.1, C445.1, C452.2, C453.2, C454.2, C455.2, C456.2, C457.2, D206.1, D207.2, D208.1, JP301.2, JP302.2, JP303.2, JP304.2, JP305.2, JP306.2, JP307.2, P201.2, P202.1, P203.2, P301.2, P302.1, P302.3, P303.1, P303.3, P303.5, P303.7, P303.9, P303.10, P401.3, P402.3, R201.2, R202.2, R203.1, R204.2, R311.1, R318.1, R319.1, R320.1, R321.1, R322.1, R407.1, R408.1, R409.1, R410.1, TR301.2, TR302.2, U201.1, U202.3, U301.2, U301.13, U301.23, U301.27, U302.1
unnamed: C202.2, C204.2, C206.2, C209.2, D203.1, L203.1
unnamed: C207.1, C210.1, C211.1, C214.1, C216.1, D204.2, L201.2, U201.3
unnamed: C207.2, R201.1
unnamed: C212.2, R202.1
unnamed: C213.1, R203.2
unnamed: C301.1, R306.2
unnamed: C302.1, C305.1, C307.1, C309.1, U301.1
unnamed: C315.1, R309.2
unnamed: C316.1, C318.1, C321.1, C325.1, U301.28
unnamed: C324.1, R310.1, U302.3
unnamed: C326.1, R311.2, R317.2, U302.2
unnamed: C329.1, P301.1, R310.2
unnamed: C408.1, C414.2, C415.1, R403.1, R407.2
unnamed: C409.1, C416.1, C417.2, R404.1, R408.2
unnamed: C410.1, C418.2, C419.1, R405.1, R409.2
unnamed: C411.1, C420.1, C421.2, R406.1, R410.2
unnamed: C414.1, C415.2, R411.1
unnamed: C416.2, C417.1, R412.2
unnamed: C418.1, C419.2, R413.1
unnamed: C420.2, C421.1, R414.2
unnamed: C432.1, R411.2, R419.2, U401.2
unnamed: C432.2, R419.1, R423.2, U401.6
unnamed: C433.1, R413.2, R420.2, U403.2
unnamed: C433.2, R420.1, R425.2, U403.6
unnamed: C434.1, R412.1, R421.2, U402.2
unnamed: C434.2, R421.1, R424.2, U402.6
unnamed: C435.1, R414.1, R422.2, U404.2
unnamed: C435.2, R422.1, R426.2, U404.6
unnamed: C438.1, C440.1, R427.1, U405.3
unnamed: C439.1, C441.1, R428.1, U406.3
unnamed: D201.1, P203.1
unnamed: D201.2, L201.1
unnamed: D202.1, P201.1
unnamed: D203.2, P202.2
unnamed: D207.1, R206.1
unnamed: D301.1, R324.1
unnamed: D301.2, TR301.3
unnamed: D302.1, R326.1
unnamed: D302.2, TR302.3
unnamed: P302.2, R312.1, R318.2
unnamed: P303.2, R313.1, R319.2
unnamed: P303.4, R314.1, R320.2
unnamed: P303.6, R315.1, R321.2
unnamed: P303.8, R316.1, R322.2
unnamed: P401.1, R401.2, R403.2
unnamed: P401.2, R401.1, R404.2
unnamed: P402.1, R402.2, R405.2
unnamed: P402.2, R402.1, R406.2
unnamed: R204.1, R205.2, U202.5
unnamed: R312.2, R313.2, U301.18
unnamed: R314.2, U301.17
unnamed: R315.2, U301.16
unnamed: R316.2, U301.15
unnamed: R323.2, TR301.1
unnamed: R325.2, TR302.1
unnamed: R415.2, U401.3
unnamed: R416.2, U403.3
unnamed: R417.1, U404.3
unnamed: R418.1, U402.3
unnamed: R429.2, U405.2, U405.6
unnamed: R430.2, U406.2, U406.6
VAA: C230.1, C231.1, C233.1, C235.1, D205.1, D208.2, L302.1, R205.1, U202.4
VCC: C201.1, C203.1, C205.1, C208.1, C224.1, C225.1, D202.2, D205.2, L202.1, U202.1, U202.2
VDD: C226.1, C227.1, C228.1, C229.1, C232.1, C234.1, C236.1, C237.1, C238.1, C313.1, C314.1, D204.1, D206.2, L301.1, R206.2, R301.1, R302.1, R303.1, R304.1, R305.1, R307.1, R308.1, R324.2, R326.2, U201.2, U302.4

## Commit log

2016-07-01 Revision 2.0
    [ADC-PCM4202-2.0-Bill-of-Materials.csv, ADC-PCM4202-2.0-Bill-of-Materials.ods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]
2016-07-01 Revision 2.0
    Remove unused schematic file
    [diffin.sch]

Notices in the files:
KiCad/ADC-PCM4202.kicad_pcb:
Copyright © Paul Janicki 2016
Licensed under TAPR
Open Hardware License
